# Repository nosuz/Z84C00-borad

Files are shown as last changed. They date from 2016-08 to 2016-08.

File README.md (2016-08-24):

# Z80(Z84C00) CPU board

This board is designed for running CP/M.

|Item|Spec|
|:--|:--|
|CPU|Z84C00|
|Memory Size|128KiB|
|CPU Clock|Max. 14MHz|
|Interface|USB|

The USB port is used as a interface to connect with the subsystem that controles a console and disk drives.

|File name|Contents|
|:---|:---|
|Z8S180.pdf|Circuit drawing(PDF)|
|Z8S180.xlsx|BOM list(Excel)|
|Z8S180.zip|zipped Gerber files|

## References

[Z80マイコンボードの製作](https://tech.nosuz.jp/2016/08/z80-cpu-borad/)

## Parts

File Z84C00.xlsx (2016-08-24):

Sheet: order
Item | Value | Footprint | Count
C | 0.1u | nosuz:C_2012 | 6
C | 0.1uF | nosuz:C_2012 | 2
C | 47pF | nosuz:C_2012 | 2
CO | SG8002DC | nosuz:DIP8_2227MC-08 | 1
CON | CONN_AVR_ISP | nosuz:AVR_ISP_2x03 | 1
CON | USB-micro-B | nosuz:USB-micro-B_Hirose | 1
CP | 4.7uF | nosuz:CP_SMD_D5 | 1
CPU | Z84C00PEG | nosuz:DIP-40_Z84C00 | 1
D | OSBL1608 | nosuz:1608_OSxx1608 | 1
D | OSHR1608 | nosuz:1608_OSxx1608 | 1
D | OSYG1608 | nosuz:1608_OSxx1608 | 1
D | OSYL1608 | nosuz:1608_OSYL1608 | 1
IC | ATMEGA64A-A | nosuz:QFP-64_14x14_Atmel64A-1.00 | 1
IMG | BITMAP_IMAGE | nosuz:Icon_Nosuz | 1
M | Mount_Hole | nosuz:HOLE-M3 | 4
MEM | M68AF127B | nosuz:SO32_STM_M68AF127B | 1
R | 10k | nosuz:R_1608 | 3
R | 27R | nosuz:R_1608 | 2
R | >3.1k | nosuz:R_1608 | 1
R | >6.2k | nosuz:R_1608 | 2
R | >8.4k | nosuz:R_1608 | 1
SW | Tactile_SW_4P | nosuz:SKRPACE010 | 1
U | FT240XS | nosuz:SSOP-24_FT240XS | 1

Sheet: mount
Ref | Value | Footprint
C1 | 0.1u | nosuz:C_2012
C5 | 0.1u | nosuz:C_2012
C6 | 0.1u | nosuz:C_2012
C7 | 0.1u | nosuz:C_2012
C8 | 0.1u | nosuz:C_2012
C9 | 0.1u | nosuz:C_2012
C4 | 0.1uF | nosuz:C_2012
C10 | 0.1uF | nosuz:C_2012
C2 | 47pF | nosuz:C_2012
C3 | 47pF | nosuz:C_2012
CO1 | SG8002DC | nosuz:DIP8_2227MC-08
CON1 | CONN_AVR_ISP | nosuz:AVR_ISP_2x03
CON2 | USB-micro-B | nosuz:USB-micro-B_Hirose
CP1 | 4.7uF | nosuz:CP_SMD_D5
CPU1 | Z84C00PEG | nosuz:DIP-40_Z84C00
D4 | OSBL1608 | nosuz:1608_OSxx1608
D2 | OSHR1608 | nosuz:1608_OSxx1608
D3 | OSYG1608 | nosuz:1608_OSxx1608
D1 | OSYL1608 | nosuz:1608_OSYL1608
IC1 | ATMEGA64A-A | nosuz:QFP-64_14x14_Atmel64A-1.00
IMG1 | BITMAP_IMAGE | nosuz:Icon_Nosuz
M1 | Mount_Hole | nosuz:HOLE-M3
M2 | Mount_Hole | nosuz:HOLE-M3
M3 | Mount_Hole | nosuz:HOLE-M3
M4 | Mount_Hole | nosuz:HOLE-M3
MEM1 | M68AF127B | nosuz:SO32_STM_M68AF127B
R3 | 10k | nosuz:R_1608
R4 | 10k | nosuz:R_1608
R9 | 10k | nosuz:R_1608
R6 | 27R | nosuz:R_1608
R7 | 27R | nosuz:R_1608
R5 | >3.1k | nosuz:R_1608
R1 | >6.2k | nosuz:R_1608
R2 | >6.2k | nosuz:R_1608
R8 | >8.4k | nosuz:R_1608
SW1 | Tactile_SW_4P | nosuz:SKRPACE010
U1 | FT240XS | nosuz:SSOP-24_FT240XS

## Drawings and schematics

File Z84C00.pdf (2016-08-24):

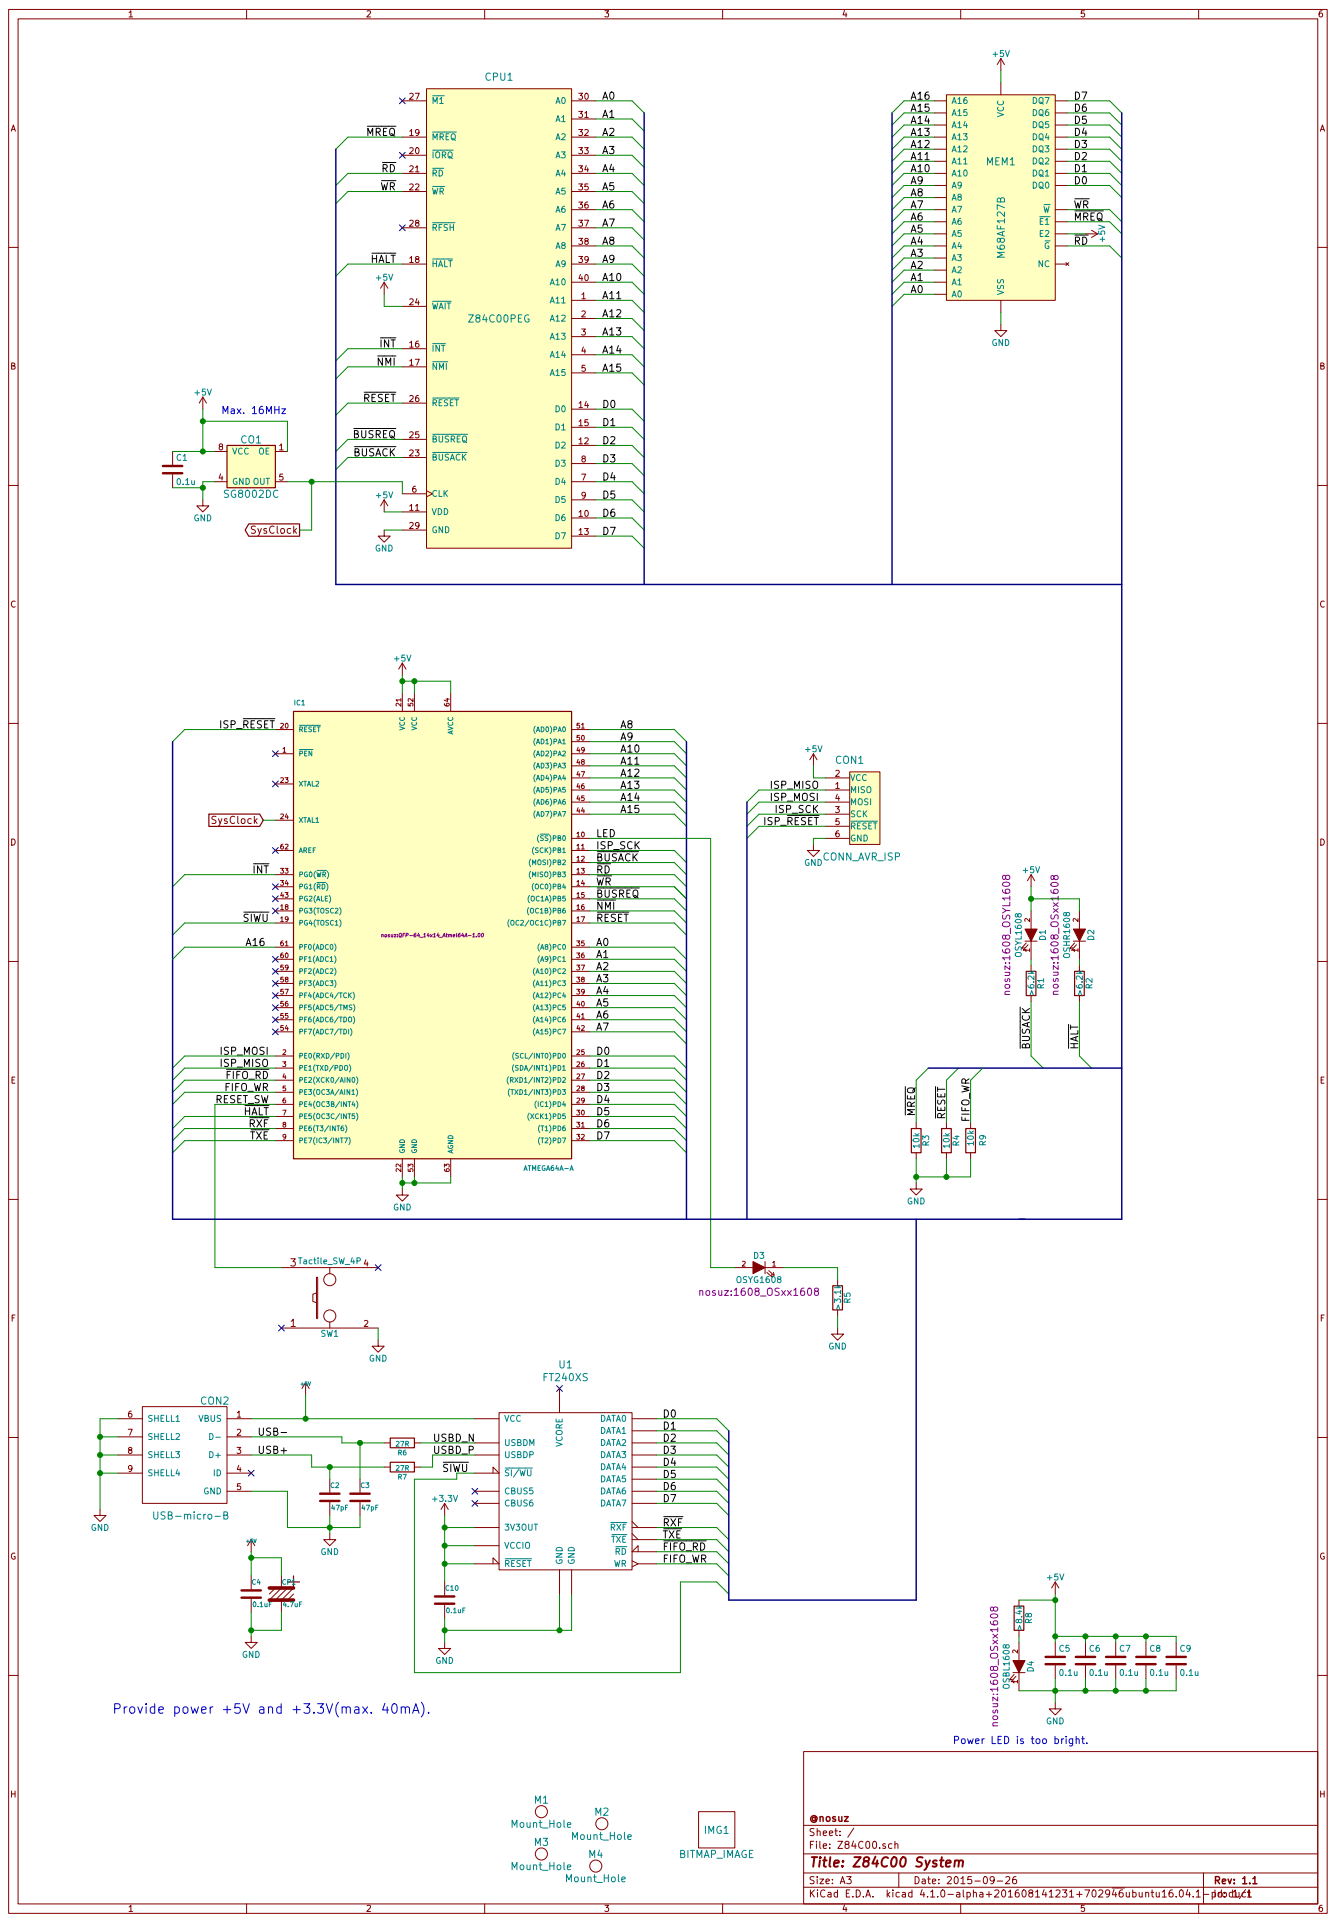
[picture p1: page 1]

RESET RD WR MREQ

File: Z84C00.sch Sheet: / @nosuz

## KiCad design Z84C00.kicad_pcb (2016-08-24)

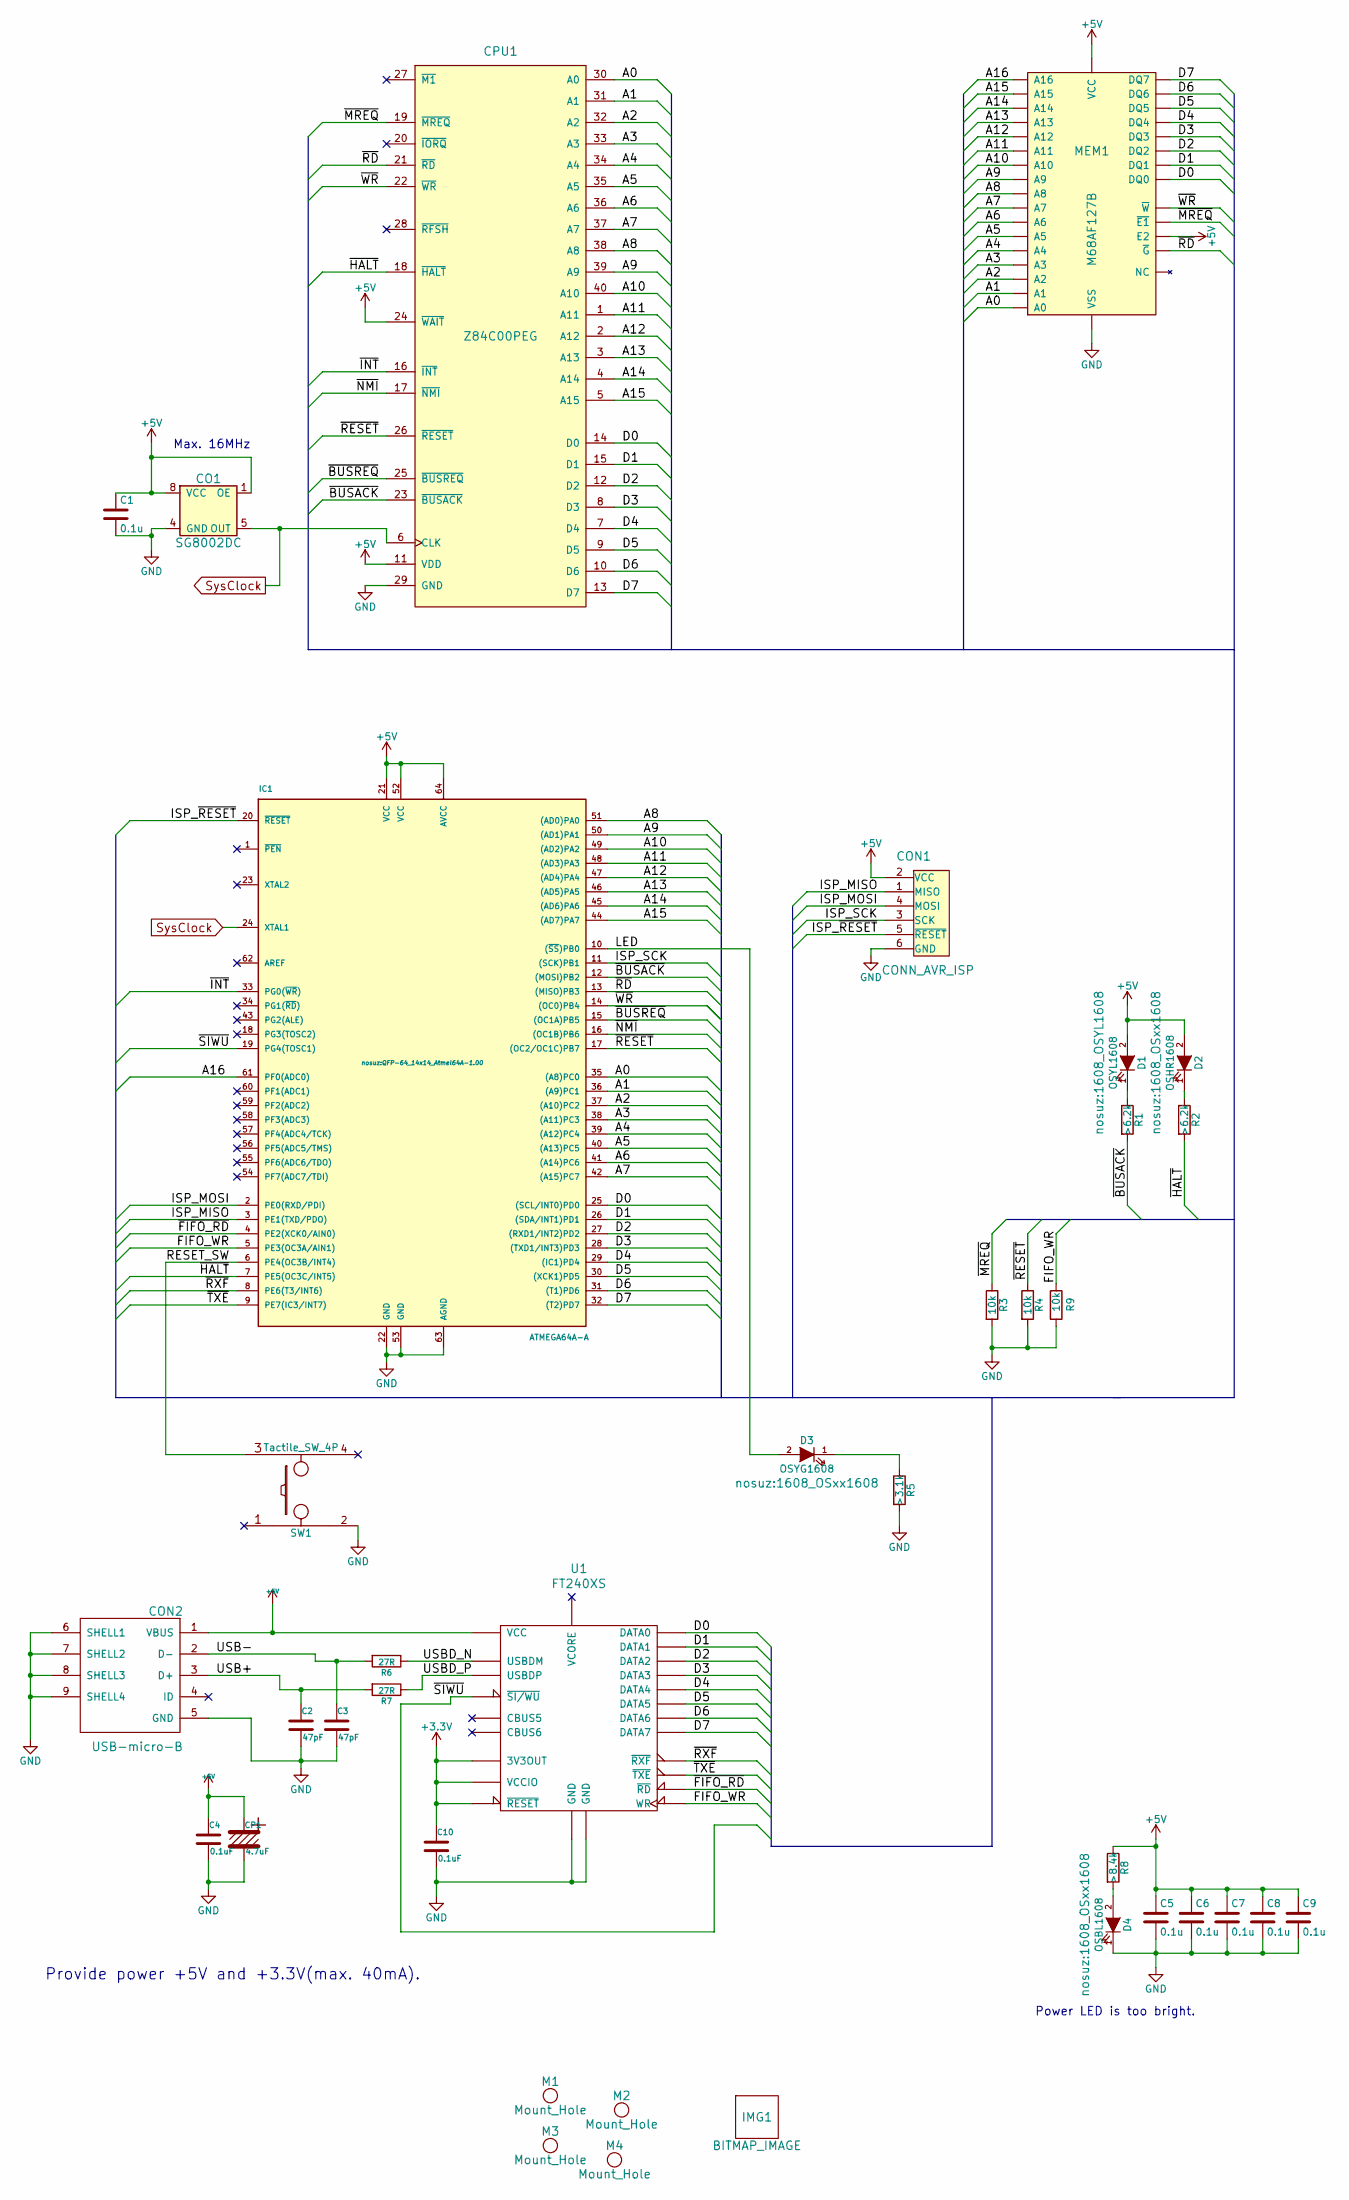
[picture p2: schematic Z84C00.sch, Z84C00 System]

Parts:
C1, C5, C6, C7, C8, C9: 0.1u; C_2012
C2, C3: 47pF; C_2012
C4, C10: 0.1uF; C_2012
CO1: SG8002DC; DIP8_2227MC-08
CON1: CONN_AVR_ISP; AVR_ISP_2x03
CON2: USB-micro-B; USB-micro-B_Hirose
CP1: 4.7uF; CP_SMD_D5
CPU1: Z84C00PEG; DIP-40_Z84C00
D1: OSYL1608; 1608_OSYL1608
D2: OSHR1608; 1608_OSxx1608
D3: OSYG1608; 1608_OSxx1608
D4: OSBL1608; 1608_OSxx1608
IC1: ATMEGA64A-A; QFP-64_14x14_Atmel64A-1.00
IMG1: BITMAP_IMAGE; Icon_Nosuz
M1, M2, M3, M4: Mount_Hole; HOLE-M3
MEM1: M68AF127B; SO32_STM_M68AF127B
R1, R2: >6.2k; R_1608
R3, R4, R9: 10k; R_1608
R5: >3.1k; R_1608
R6, R7: 27R; R_1608
R8: >8.4k; R_1608
SW1: Tactile_SW_4P; SKRPACE010
U1: FT240XS; SSOP-24_FT240XS

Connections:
+3V3: C10.1, U1.3 (VCCIO), U1.15 (3V3OUT), U1.16 (~RESET)
+5V: C1.1, C4.1, C5.1, C6.1, C7.1, C8.1, C9.1, CO1.1 (OE), CO1.8 (VCC), CON1.2 (VCC), CON2.1 (VBUS), CP1.1, CPU1.11 (VDD), CPU1.24 (~WAIT), D1.2 (A), D2.2 (A), IC1.21 (VCC), IC1.52 (VCC), IC1.64 (AVCC), MEM1.30 (E2), MEM1.32 (VCC), R8.1, U1.18 (VCC)
/A0: CPU1.30 (A0), IC1.35 ((A8)PC0), MEM1.12 (A0)
/A1: CPU1.31 (A1), IC1.36 ((A9)PC1), MEM1.11 (A1)
/A2: CPU1.32 (A2), IC1.37 ((A10)PC2), MEM1.10 (A2)
/A3: CPU1.33 (A3), IC1.38 ((A11)PC3), MEM1.9 (A3)
/A4: CPU1.34 (A4), IC1.39 ((A12)PC4), MEM1.8 (A4)
/A5: CPU1.35 (A5), IC1.40 ((A13)PC5), MEM1.7 (A5)
/A6: CPU1.36 (A6), IC1.41 ((A14)PC6), MEM1.6 (A6)
/A7: CPU1.37 (A7), IC1.42 ((A15)PC7), MEM1.5 (A7)
/A8: CPU1.38 (A8), IC1.51 ((AD0)PA0), MEM1.27 (A8)
/A9: CPU1.39 (A9), IC1.50 ((AD1)PA1), MEM1.26 (A9)
/A10: CPU1.40 (A10), IC1.49 ((AD2)PA2), MEM1.23 (A10)
/A11: CPU1.1 (A11), IC1.48 ((AD3)PA3), MEM1.25 (A11)
/A12: CPU1.2 (A12), IC1.47 ((AD4)PA4), MEM1.4 (A12)
/A13: CPU1.3 (A13), IC1.46 ((AD5)PA5), MEM1.28 (A13)
/A14: CPU1.4 (A14), IC1.45 ((AD6)PA6), MEM1.3 (A14)
/A15: CPU1.5 (A15), IC1.44 ((AD7)PA7), MEM1.31 (A15)
/A16: IC1.61 (PF0(ADC0)), MEM1.2 (A16)
/D0: CPU1.14 (D0), IC1.25 ((SCL/INT0)PD0), MEM1.13 (DQ0), U1.24 (DATA0)
/D1: CPU1.15 (D1), IC1.26 ((SDA/INT1)PD1), MEM1.14 (DQ1), U1.4 (DATA1)
/D2: CPU1.12 (D2), IC1.27 ((RXD1/INT2)PD2), MEM1.15 (DQ2), U1.2 (DATA2)
/D3: CPU1.8 (D3), IC1.28 ((TXD1/INT3)PD3), MEM1.17 (DQ3), U1.9 (DATA3)
/D4: CPU1.7 (D4), IC1.29 ((IC1)PD4), MEM1.18 (DQ4), U1.1 (DATA4)
/D5: CPU1.9 (D5), IC1.30 ((XCK1)PD5), MEM1.19 (DQ5), U1.7 (DATA5)
/D6: CPU1.10 (D6), IC1.31 ((T1)PD6), MEM1.20 (DQ6), U1.8 (DATA6)
/D7: CPU1.13 (D7), IC1.32 ((T2)PD7), MEM1.21 (DQ7), U1.5 (DATA7)
/FIFO_WR: IC1.5 (PE3(OC3A/AIN1)), R9.1, U1.12 (WR)
/ISP_MISO: CON1.1 (MISO), IC1.3 (PE1(TXD/PDO))
/ISP_MOSI: CON1.4 (MOSI), IC1.2 (PE0(RXD/PDI))
/ISP_SCK: CON1.3 (SCK), IC1.11 ((SCK)PB1)
/ISP_~RESET: CON1.5 (~RESET), IC1.20 (~RESET)
/LED: D3.2 (A), IC1.10 ((~SS~)PB0)
/RESET_SW: IC1.6 (PE4(OC3B/INT4)), SW1.3
/USB+: C2.1, CON2.3 (D+), R7.2
/USB-: C3.1, CON2.2 (D-), R6.2
/USBD_N: R6.1, U1.14 (USBDM)
/USBD_P: R7.1, U1.13 (USBDP)
/~BUSACK: CPU1.23 (~BUSACK), IC1.12 ((MOSI)PB2), R1.2
/~BUSREQ: CPU1.25 (~BUSREQ), IC1.15 ((OC1A)PB5)
/~FIFO_RD: IC1.4 (PE2(XCK0/AIN0)), U1.11 (~RD)
/~HALT: CPU1.18 (~HALT), IC1.7 (PE5(OC3C/INT5)), R2.2
/~INT: CPU1.16 (~INT), IC1.33 (PG0(~WR~))
/~MREQ: CPU1.19 (~MREQ), MEM1.22 (~E1), R3.1
/~NMI: CPU1.17 (~NMI), IC1.16 ((OC1B)PB6)
/~RD: CPU1.21 (~RD), IC1.13 ((MISO)PB3), MEM1.24 (~G)
/~RESET: CPU1.26 (~RESET), IC1.17 ((OC2/OC1C)PB7), R4.1
/~RXF: IC1.8 (PE6(T3/INT6)), U1.21 (~RXF)
/~SIWU: IC1.19 (PG4(TOSC1)), U1.10 (~SI/WU)
/~TXE: IC1.9 (PE7(IC3/INT7)), U1.20 (~TXE)
/~WR: CPU1.22 (~WR), IC1.14 ((OC0)PB4), MEM1.29 (~W)
GND: C1.2, C2.2, C3.2, C4.2, C5.2, C6.2, C7.2, C8.2, C9.2, C10.2, CO1.4 (GND), CON1.6 (GND), CON2.5 (GND), CON2.6 (SHELL1), CON2.7 (SHELL2), CON2.8 (SHELL3), CON2.9 (SHELL4), CP1.2, CPU1.29 (GND), D4.1 (K), IC1.22 (GND), IC1.53 (GND), IC1.63 (AGND), MEM1.16 (VSS), R3.2, R4.2, R5.2, R9.2, SW1.2, U1.6 (GND), U1.19 (GND)
unnamed: D1.1 (K), R1.1
unnamed: D2.1 (K), R2.1
unnamed: D3.1 (K), R5.1
unnamed: D4.2 (A), R8.2
SysClock: CO1.5 (OUT), CPU1.6 (CLK), IC1.24 (XTAL1)

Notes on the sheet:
Provide power +5V and +3.3V(max. 40mA).
Max. 16MHz
Power LED is too bright.

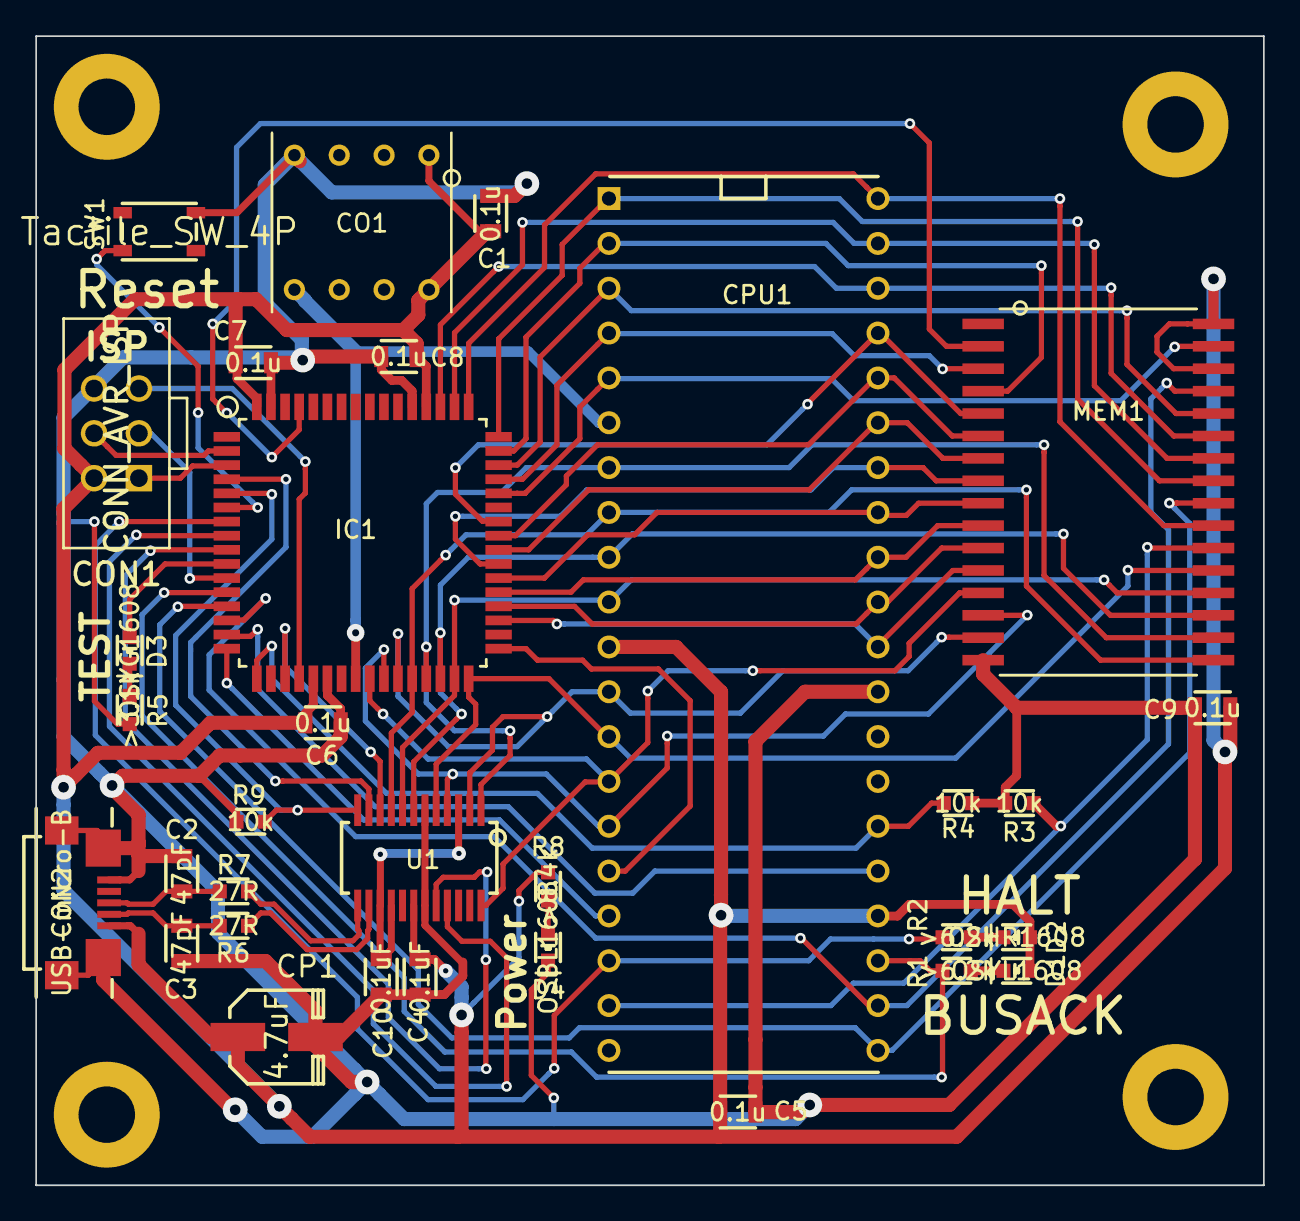
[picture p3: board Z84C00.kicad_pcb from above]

Board: 2 copper layers, 69.6 x 65.1 mm, 37 parts (1 on the bottom side), 57 nets.
